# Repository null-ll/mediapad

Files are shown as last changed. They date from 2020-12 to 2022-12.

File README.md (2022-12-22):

# mediapad

mediapad

A simple 3d printed volume/media controller macropad with 3 MX-style keyswitches and 8 customizable WS2812B RGB LEDs! Runs on [QMK firmware](https://github.com/qmk/qmk_firmware).

Case is still a WIP. Current version requires drilling holes into the top housing for the screws. The USB cutout also seems a bit off but that could just be poor tolerances from my 3d printer.

# usage
layout

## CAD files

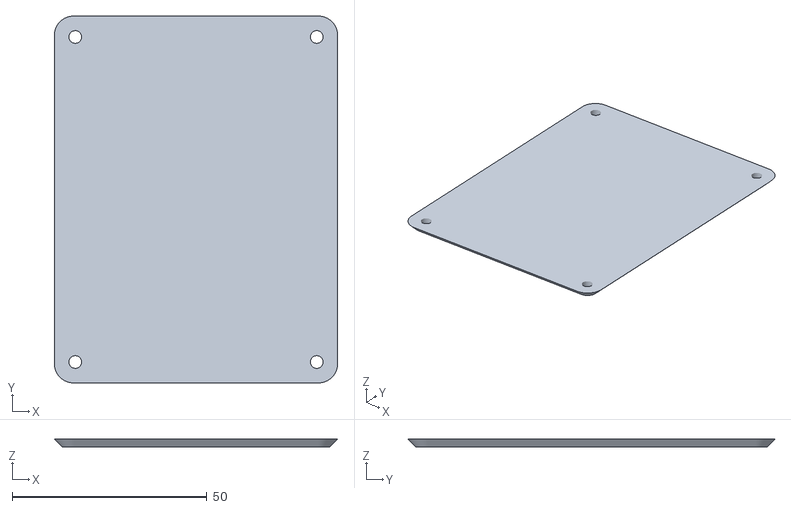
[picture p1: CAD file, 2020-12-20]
case/Bottom.stl
72.7 x 94.1 x 2.00

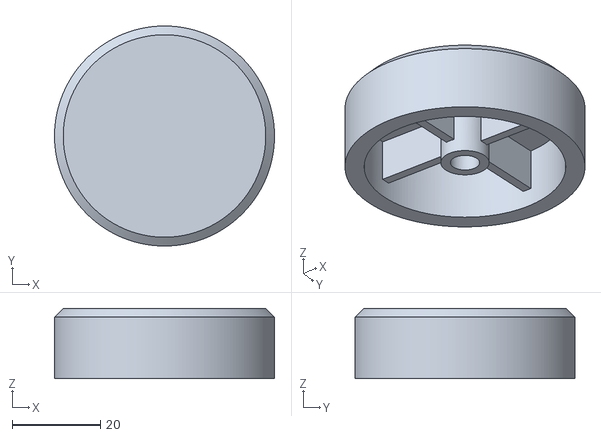
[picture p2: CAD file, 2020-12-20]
case/Knob.stl
50.0 x 50.0 x 16.0

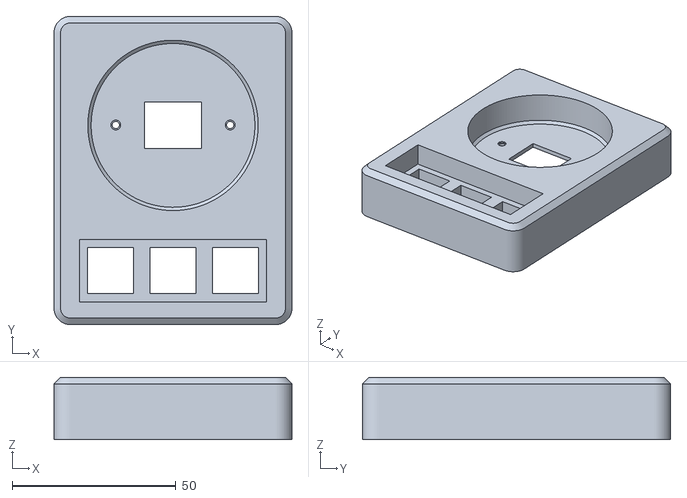
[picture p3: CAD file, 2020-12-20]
case/Top.stl
72.7 x 94.1 x 19.0

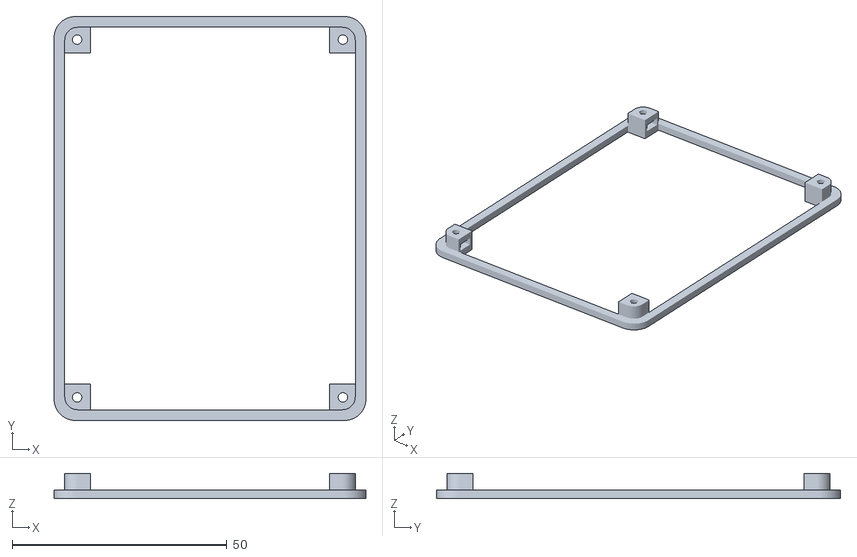
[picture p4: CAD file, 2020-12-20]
case/Middle.stl
72.7 x 94.1 x 5.90

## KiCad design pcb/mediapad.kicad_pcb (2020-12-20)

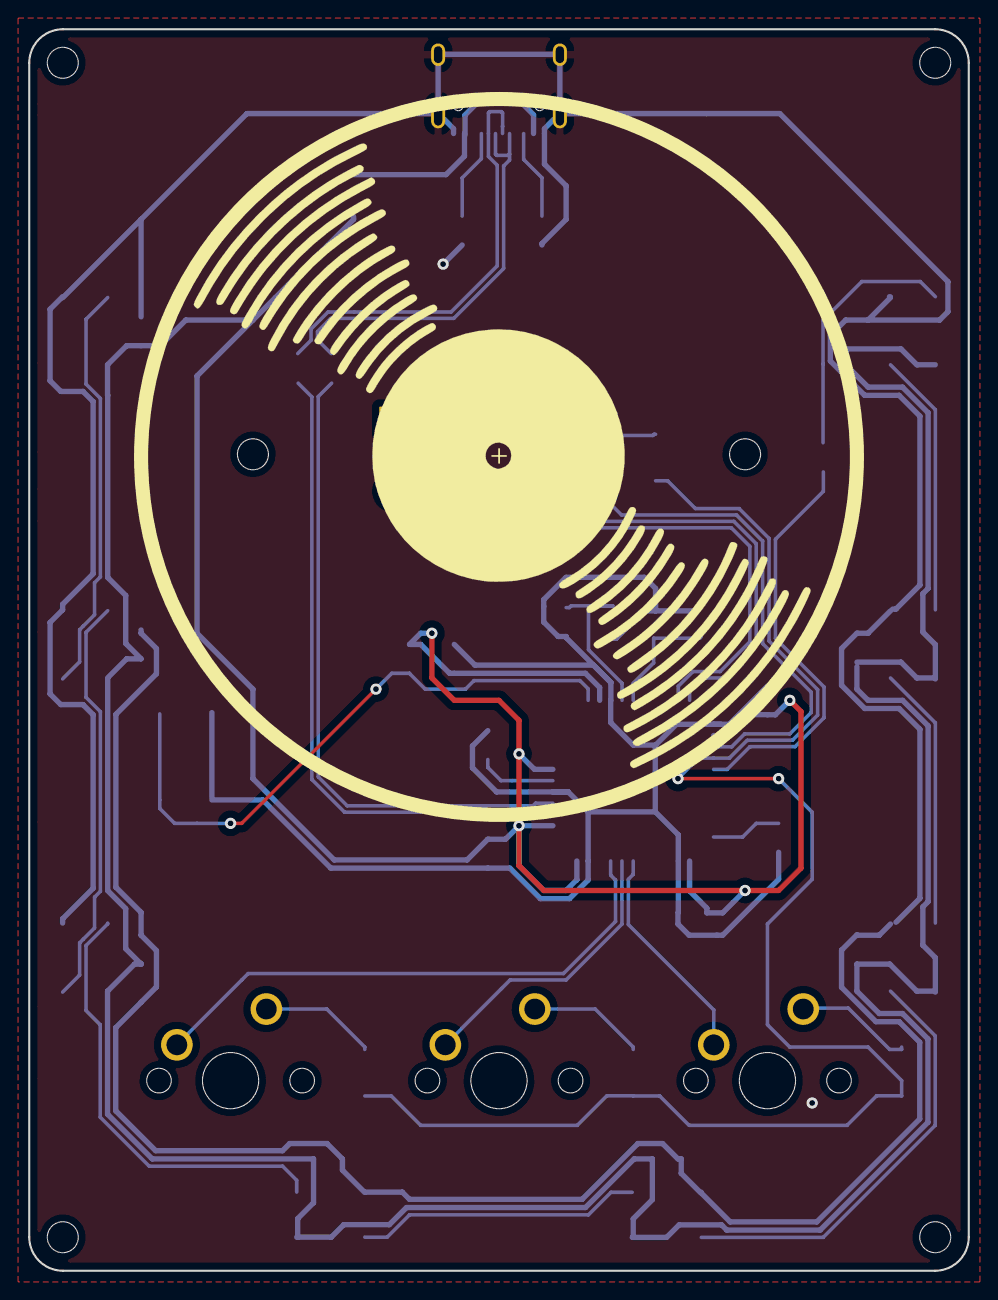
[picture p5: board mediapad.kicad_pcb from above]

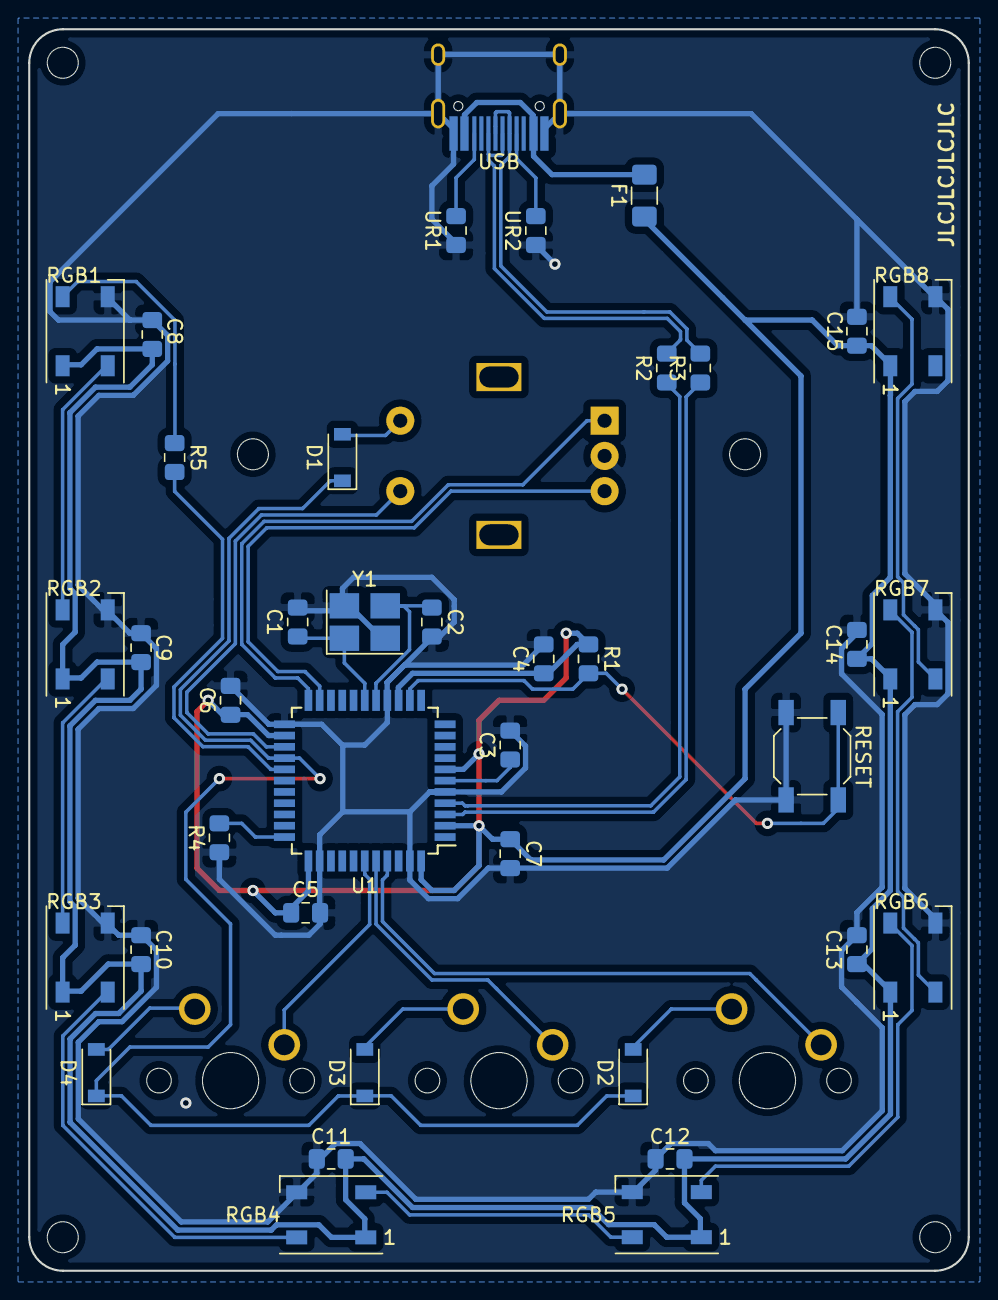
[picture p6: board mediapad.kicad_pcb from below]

Board: 2 copper layers, 66.7 x 88.1 mm, 49 parts (39 on the bottom side), 34 nets.

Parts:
C1, C2: 22pF; C_0805_2012Metric_Pad1.15x1.40mm_HandSolder
C3: 1uF; C_0805_2012Metric_Pad1.15x1.40mm_HandSolder
C4, C5, C6, C8, C9, C10, C11, C12, C13, C14, C15: 0.1uF; C_0805_2012Metric_Pad1.15x1.40mm_HandSolder
C7: 10uF; C_0805_2012Metric_Pad1.15x1.40mm_HandSolder
D1, D2, D3, D4: D_Small; D_SOD-123
F1: 500mA; Fuse_1206_3216Metric_Pad1.42x1.75mm_HandSolder
H1, H2, H3, H4, H5, H6: MountingHole; MountingHole_2.2mm_M2
MX1, MX2, MX3: MX-NoLED; MXOnly-1U-NoLED
R1, R4: 10k; R_0805_2012Metric_Pad1.15x1.40mm_HandSolder
R2, R3: 22; R_0805_2012Metric_Pad1.15x1.40mm_HandSolder
R5: 500; R_0805_2012Metric_Pad1.15x1.40mm_HandSolder
RESET: SW_Push; SW_SPST_SKQG_WithoutStem
RGB1, RGB2, RGB3, RGB4, RGB5, RGB6, RGB7, RGB8: WS2812B; LED_WS2812B_PLCC4_5.0x5.0mm_P3.2mm
ROTARY ENCODER: Rotary_Encoder_Switch; RotaryEncoder_Alps_EC11E-Switch_Vertical_H20mm
U1: ATmega32U4-AU; TQFP-44_10x10mm_P0.8mm
UR1, UR2: 5.1k; R_0805_2012Metric_Pad1.15x1.40mm_HandSolder
USB: HRO-TYPE-C-31-M-12; HRO-TYPE-C-31-M-12-HandSoldering
Y1: 16MHz; Crystal_SMD_3225-4Pin_3.2x2.5mm_HandSoldering

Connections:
+5V: C4.1, C5.1, C6.1, C7.1, C8.1, C9.1, C10.1, C11.1, C12.1, C13.1, C14.1, C15.1, F1.1, R1.1, RGB1.1, RGB2.1, RGB3.1, RGB4.1, RGB5.1, RGB6.1, RGB7.1, RGB8.1, U1.2, U1.7, U1.14, U1.24, U1.34, U1.44
COL0: ROTARY ENCODER.S1, U1.25
COL1: MX1.1, U1.41
COL2: MX2.1, U1.40
COL3: MX3.1, U1.39
D+: R2.2, USB.6, USB.8
D-: R3.2, USB.5, USB.7
EN1: ROTARY ENCODER.A, U1.22
EN2: ROTARY ENCODER.B, U1.21
GND: C1.2, C2.2, C3.2, C4.2, C5.2, C6.2, C7.2, C8.2, C9.2, C10.2, C11.2, C12.2, C13.2, C14.2, C15.2, R4.1, RESET.2, RGB1.3, RGB2.3, RGB3.3, RGB4.3, RGB5.3, RGB6.3, RGB7.3, RGB8.3, ROTARY ENCODER.C, U1.5, U1.15, U1.23, U1.35, U1.43, UR1.1, UR2.1, USB.1, USB.12, USB.13, Y1.2, Y1.4
unnamed: C1.1, U1.17, Y1.1
unnamed: C2.1, U1.16, Y1.3
unnamed: C3.1, U1.6
unnamed: D1.2, ROTARY ENCODER.S2
unnamed: D2.2, MX1.2
unnamed: D3.2, MX2.2
unnamed: D4.2, MX3.2
unnamed: R2.1, U1.4
unnamed: R3.1, U1.3
unnamed: R4.2, U1.33
unnamed: R5.1, RGB1.4
unnamed: RGB1.2, RGB2.4
unnamed: RGB2.2, RGB3.4
unnamed: RGB3.2, RGB4.4
unnamed: RGB4.2, RGB5.4
unnamed: RGB5.2, RGB6.4
unnamed: RGB6.2, RGB7.4
unnamed: RGB7.2, RGB8.4
unnamed: UR1.2, USB.10
unnamed: UR2.2, USB.4
RESET: R1.2, RESET.1, U1.13
RGBIN: R5.2, U1.27
ROW0: D1.1, D2.1, D3.1, D4.1, U1.26
VCC: F1.2, USB.2, USB.11

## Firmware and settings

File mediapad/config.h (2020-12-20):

#pragma once

#include "config_common.h"

/* USB Device descriptor parameter */
#define VENDOR_ID       0x1C8E
#define PRODUCT_ID      0x0001
#define DEVICE_VER      0x0002
#define MANUFACTURER    noahl
#define PRODUCT         mediapad
#define DESCRIPTION     mediapad

/* key matrix size */
#define MATRIX_ROWS 1
#define MATRIX_COLS 4

/* key matrix pins */
#define MATRIX_ROW_PINS { D6 }
#define MATRIX_COL_PINS { D4, F0, F1, F4 }
#define UNUSED_PINS

/* COL2ROW or ROW2COL */
#define DIODE_DIRECTION COL2ROW

/* Set 0 if debouncing isn't needed */
#define DEBOUNCING_DELAY 5

/* Rotary Encoder */
#define ENCODERS_PAD_A { D5 }
#define ENCODERS_PAD_B { D3 }
#define ENCODER_RESOLUTION 4
#define TAP_CODE_DELAY 10

#define RGB_DI_PIN D7
#define RGBLIGHT_EFFECT_BREATHING
#define RGBLIGHT_EFFECT_RAINBOW_SWIRL
#define RGBLIGHT_EFFECT_RAINBOW_MOOD
#define RGBLIGHT_EFFECT_SNAKE
#define RGBLIGHT_EFFECT_TWINKLE
#define RGBLED_NUM 8
#define RGBLIGHT_HUE_STEP 10
#define RGBLIGHT_VAL_STEP 17
#define RGBLIGHT_SAT_STEP 17
